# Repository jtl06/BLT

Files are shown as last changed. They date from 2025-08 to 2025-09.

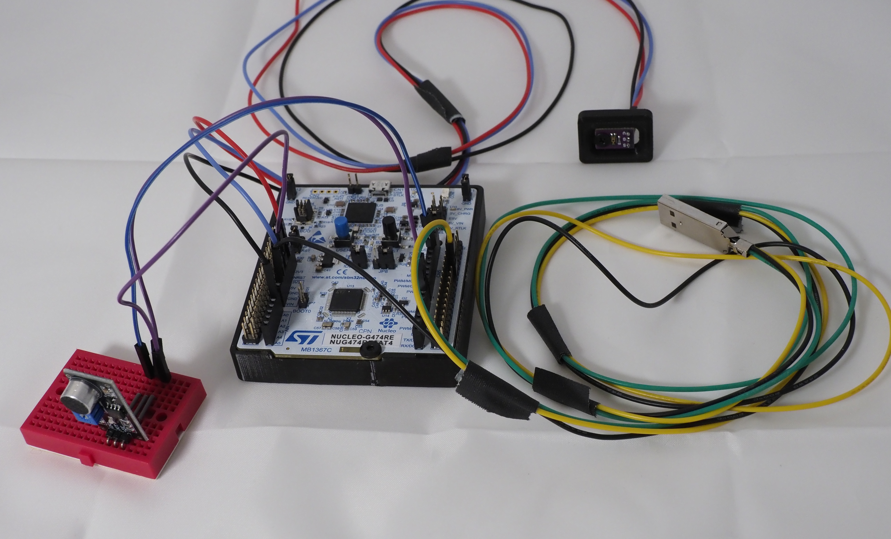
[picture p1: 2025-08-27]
docs/pictures/everything.JPG

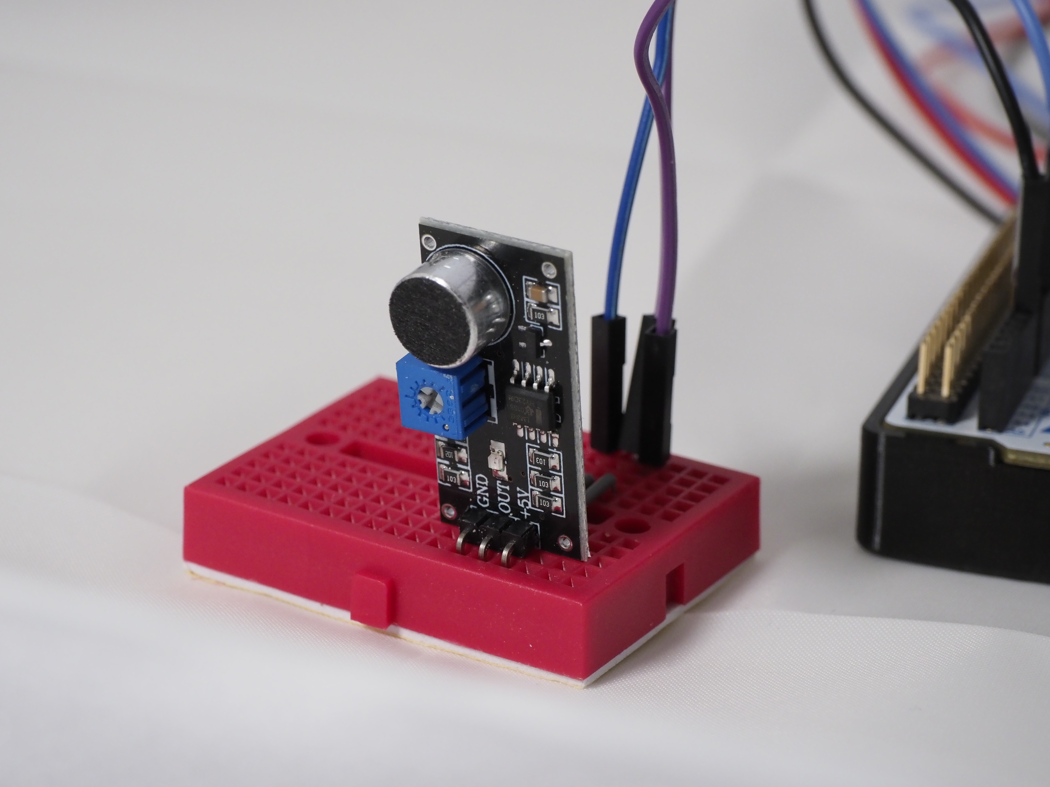
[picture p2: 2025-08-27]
docs/pictures/microphone.JPG

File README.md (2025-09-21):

# BLT - Better Latency Tester
The Better Latency Tester (BLT) is an open device for click to photon latency measurements in video games. It enables evaluation of game settings, monitors, and mice through reproducible, end-to-end latency data.

BLT features include:
- Automatic or manual threshold calibration
- Run batched, self-triggered tests via USB mouse HID inputs, with latency logging
- Microphone triggered tests for testing mouse latency

---
## Demo
https://github.com/user-attachments/assets/7085f5da-f47d-4a11-8dff-cdf1d9c3fb22
TEMT6000 Phototransistor Module             |  BLT Hardware
:-------------------------:|:-------------------------:
   |  

## Limitations
- Numbers should only be used to compare relative values, as the BLT has not been calibrated against an external reference such as a high speed (1000fps+) camera.
- Sample size requirements, latency results are randomly distributed, to get statistically significant results, a large amount of samples is required.

## Sample Data
### Vsync On vs Off vs Reflex
| Settings | n | Median | Mean | Std Dev | Min | Max |
|---|-----|---|---|---|---|---|
| 60hz, 60fps, Vsync On, Reflex Off | 100 | 74.101 | 74.507 | 5.222 | 66.134 | 93.211 |
| 60hz, 60fps, Vsync On, Reflex On | 100 | 74.951 | 74.572 | 4.871 | 66.426 | 82.621 |
| 60hz, 64fps Vsync Off, Reflex Off | 100 | 31.338  | 31.316  | 6.524 | 18.439 | 45.391 |
| 60hz, 64fps Vsync Off, Reflex On  | 100 | 27.529  | 27.335  | 6.268 | 6.569 | 40.024 |
| 240hz, 240fps, Vsync On, Reflex Off | 100 | 13.261 | 13.839 | 2.507 | 9.621 | 19.396 |
| 240hz, 240fps, Vsync On, Reflex On | 100 | 13.359 | 13.898 | 2.521 | 4.972 | 20.301 |
| 240hz, 240fps Vsync Off, Reflex Off | 100 | 10.304  | 10.457  | 1.900 | 5.338 | 15.056 |
| 240hz, 240fps Vsync Off, Reflex On  | 100 | 10.599  | 10.479  | 1.967 | 6.098 | 16.648 |

Tested in Counter-Strike 2, times in ms. Low settings. See docs for raw data. Note: CS2 implements a minimum framerate cap of 64fps when not using vsync.

### Reflex, with higher GPU Load (to maximize impact of render pipeline load)
|Settings|n|Median|Mean|Std Dev|Min|Max|
|---|-----|---|---|---|---|---|
|240hz, uncapped (~220fps), Vsync Off, Reflex Off|100|17.723|17.586|2.213|5.388|22.063|
|240hz, uncapped (~220fps),  Vsync Off, Reflex On|100|14.364|14.361|1.862|8.834|18.980|

High settings test, with greater GPU load, Reflex has a larger, more measurable improvement.  

### Mouse Testing using Mic Mode
| Settings | n | Median | Mean | Std Dev | Min | Max |
|---|-----|---|---|---|---|---|
| VXE MAD R, 125hz | 25 | 24.294  | 24.677 | 2.441 | 21.067 | 29.780 |
| VXE MAD R, 250hz | 25 | 21.855 | 21.915 | 1.775 | 18.865 | 25.430 |
| VXE MAD R, 500hz | 25 | 21.030  | 21.324  | 1.726 | 17.996 | 24.752 |
| VXE MAD R, 1000hz  | 25 | 20.561 | 20.346 | 1.506 | 17.291 | 22.533 |
| VXE MAD R, 2000hz | 25 | 20.566 | 20.729 | 1.588 | 17.852 | 23.397 |
| VXE MAD R, 4000hz | 25 | 20.518 | 20.561 | 1.100 | 19.012 | 23.409 |
| VXE MAD R, 8000hz| 25 | 19.558  | 20.029  | 1.572 | 17.983 | 23.513 |
| Razer Viper Pro V2, 4000hz  | 25 | 20.146  | 20.056  | 1.386 | 17.637 | 23.038 |
| Trigger Mode, 1000hz  | 100 | 20.146  | 20.056  | 1.386 | 17.637 | 23.038 |

Tested at 240hz, Low settings, Reflex On. At these sample size, could not find significant improvement above 1khz. TODO: Larger sample sizes

## Requirements
### Hardware
- NUCLEO-G474RE (or compatible STM32 with USB FS + ADC)
- TEMT6000 phototransistor (or photodiode)
- LM393 microphone module
- 2 USB cables (one for ST-Link serial comms, one for the USB HID Device)
### Software
- [Arm GNU Toolchain](https://developer.arm.com/downloads/-/arm-gnu-toolchain) (arm-none-eabi-gcc, make)
- [STM32CubeMX](https://www.st.com/en/development-tools/stm32cubemx.html) (for .ioc regeneration)
- Python 3.9+ (for PC app)

## Instructions
### HW Pinout  
| Function | MCU Pin | Periph/Chan | Notes |
|---|---|---|---|
| **USB D+/D-** | PA12/PA11 | USB_FS | To PC (mouse HID signal) |
| **Light Sensor (Photodiode/PT)**  | PA0 | ADC1 INx | Analog input |
| **Microphone (click detect)** | PA8 | GPIO | LM393 microphone module|
| **Serial Comms** | PA2/PA3 | LPUART TX/RX | Bidirectional communications for app control|
### Flashing
Flash via ST-LINK, using makefile and command ```make flash```

### Operation
1. Plug the USB cable from the board into your PC under test (should enumerate as a USB HID device).
2. Place the photodiode over the area that will recieve the flash. If using mic mode, place the microphone module near the mouse click.
3. Windows: launch the prebuilt GUI executable BLT-gui.exe, Linux/macOS: run the Python app directly with ```python blt_gui.py```
4. Follow GUI to Set Mode, Calibrate, and Test. Data can be exported via CSV.

## Architecture
- MCU
  - USB HID mouse
  - ADC w/ circular DMA: light sensor
  - 1Mhz TIM clock for 1us resolution
  - LPUART over ST-Link VCP: command IO and telemetry

## Timing
BLT

Mode 2: USB Trigger, latency = t<sub>1</sub> - t<sub>0</sub>u

Mode 3: Mic Trigger, latency = t<sub>1</sub> - t<sub>0</sub>m

ISR period stats: avg=400 us, min=391 us, max=409 us, jitter=±9 us

## Roadmap
- Finish Readme
- Linux Sidecar for data handling
- Custom PCB for manufacturing
- Switch to MCU/board with USB HS PHY support for 8khz polling rate

> Inspired by the NVIDIA LDAT. This project is independent and unaffiliated with NVIDIA.

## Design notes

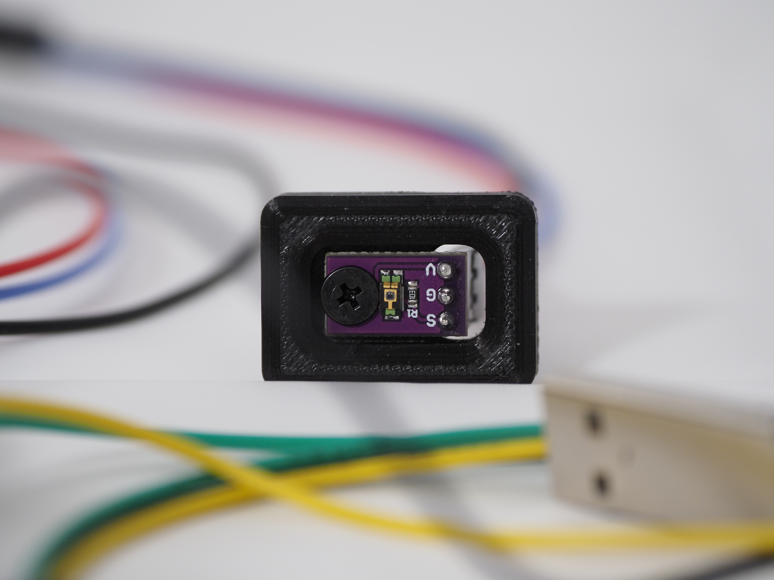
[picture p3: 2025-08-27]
docs/pictures/phototransistor.JPG

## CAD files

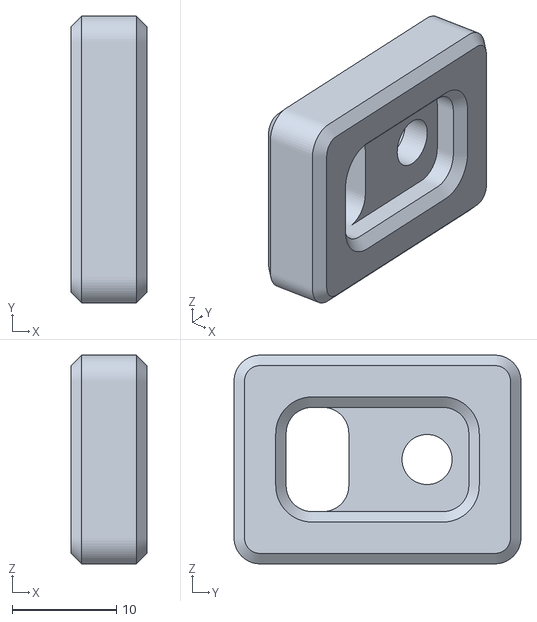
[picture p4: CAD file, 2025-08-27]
CAD files/TEMT6000 Case.stl
7.25 x 27.5 x 20.0

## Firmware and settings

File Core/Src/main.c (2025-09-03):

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
/* Includes ------------------------------------------------------------------*/
#include "main.h"
#include "adc.h"
#include "dma.h"
#include "usart.h"
#include "tim.h"
#include "usb_device.h"
#include "gpio.h"

/* USER CODE BEGIN Includes */
#include "usbd_hid.h"
#include <stdio.h>
#include <stdbool.h>
#include <stdint.h>
#include <string.h>
#include <stdlib.h>
#include <inttypes.h>
#include "isr_log.h"


/* USER CODE END Includes */

/* USER CODE BEGIN PTD */
typedef enum {
  MODE1_CALIBRATION = 1,
  MODE2_TRIGGER     = 2,
  MODE3_MIC         = 3,
} blt_mode_t;

/* USER CODE END PTD */

/* USER CODE BEGIN PD */
#define FW_VERSION "BLT 0.1.1"

#define ADC_BUF_LEN 256u
#define MODE2_SPACING_US 5000000u // 5 s
#define MIC_DEBOUNCE_US 200000u  // 200 ms

#define ADC_SAMPLE_PERIOD_US 3u // 3us

/* USER CODE END PD */


/* USER CODE BEGIN PV */
extern USBD_HandleTypeDef hUsbDeviceFS;

static uint16_t          g_light_threshold = 200;
static volatile uint32_t g_tests_remaining = 0;
static uint32_t          g_trial_idx = 0;

static volatile bool     g_waiting_for_light = false;
static volatile uint32_t g_t_start_us = 0;
static uint32_t          g_last_launch_us = 0;
static volatile uint32_t g_last_mic_us = 0;

static uint8_t  rx_byte;
static char     cmd_buf[96];
static uint8_t  cmd_len = 0;

volatile uint16_t g_adc_dma_buf[ADC_BUF_LEN];

static volatile blt_mode_t g_mode = MODE1_CALIBRATION;

static volatile uint32_t g_last_idx = 0;

//unused, for debug if needed
// static volatile bool g_btn_click_req = false; 



/* USER CODE END PV */

void SystemClock_Config(void);
/* USER CODE BEGIN PFP */
void send_mouse_click(void);
static inline uint16_t adc_latest_sample(void); 
static void uart_start_rx_it(void);
static void send_line(const char *s);
static void handle_cmd(const char *cmd);

static inline uint32_t adc_write_idx(void);
static bool detect_cross_and_stamp(uint16_t thr, uint32_t* t1_out);
static void isr_log_dump_stats(void);


/* USER CODE END PFP */

/* USER CODE BEGIN 0 */
int _write(int file, char *ptr, int len)
{
  HAL_UART_Transmit(&hlpuart1, (uint8_t*)ptr, len, HAL_MAX_DELAY);
  return len;
}

/* USER CODE END 0 */

/**
  * @brief  The application entry point.
  * @retval int
  */
int main(void)
{

  /* MCU Configuration--------------------------------------------------------*/

  /* Reset of all peripherals, Initializes the Flash interface and the Systick. */
  HAL_Init();

  /* Configure the system clock */
  SystemClock_Config();

  /* Initialize all configured peripherals */
  MX_GPIO_Init();
  MX_DMA_Init();
  MX_LPUART1_UART_Init();
  MX_ADC1_Init();
  MX_TIM2_Init();
  MX_USB_Device_Init();
  /* USER CODE BEGIN 2 */
  
  HAL_ADCEx_Calibration_Start(&hadc1, ADC_SINGLE_ENDED);

  if (HAL_ADC_Start_DMA(&hadc1, (uint32_t*)g_adc_dma_buf, ADC_BUF_LEN) != HAL_OK)
  {
    Error_Handler();
  }

  printf("Continuous ADC-DMA running, buf=%u samples\r\n", ADC_BUF_LEN);
  printf("Initialized %s\r\n", FW_VERSION);
  HAL_TIM_Base_Start(&htim2);
  uart_start_rx_it();
  // printf("%lu\n", USBD_HID_GetPollingInterval(&hUsbDeviceFS)); // send polling rate
  
  
  /* USER CODE END 2 */

  /* Infinite loop */
  /* USER CODE BEGIN WHILE */
while (1) {
  uint32_t now_us = tim2_us();

  // MODE2: launch trials periodically, using USB as trigger
  if (g_mode == MODE2_TRIGGER && g_tests_remaining && !g_waiting_for_light) {
    if ((now_us - g_last_launch_us) >= MODE2_SPACING_US) {
      g_last_launch_us = tim2_us();
      g_last_idx = adc_write_idx();
      g_t_start_us = tim2_us();  //start time
      g_waiting_for_light = true;
      send_mouse_click();
    }
  }
  __WFI();
    /* USER CODE END WHILE */

    /* USER CODE BEGIN 3 */
  }
  /* USER CODE END 3 */
}

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
/* USER CODE BEGIN 4 */
static inline uint16_t adc_latest_sample(void)
{
    uint32_t dma_remaining = __HAL_DMA_GET_COUNTER(&hdma_adc1);
    uint32_t idx           = (ADC_BUF_LEN - dma_remaining) & (ADC_BUF_LEN-1);
    return g_adc_dma_buf[idx];
}


static inline uint32_t adc_write_idx(void){
    // NDTR = how many transfers LEFT; write index = prod
    uint32_t ndtr = __HAL_DMA_GET_COUNTER(&hdma_adc1);
    return (ADC_BUF_LEN - ndtr) & (ADC_BUF_LEN - 1);
}

static bool detect_cross_and_stamp(uint16_t thr, uint32_t* t1_out){
    uint32_t write = adc_write_idx();
    uint32_t idx   = g_last_idx;

    while (idx != write) {
        uint16_t s = g_adc_dma_buf[idx];
        if (s >= thr) {
            uint32_t now = tim2_us(); // tim2 ticks
            // How far behind "now" that sample is, in samples (mod ring)
            uint32_t samples_behind = (write - idx) & (ADC_BUF_LEN - 1);
            // sample time = 3 us
            uint32_t ticks_behind = samples_behind * ADC_SAMPLE_PERIOD_US;
            *t1_out = now - ticks_behind;
            g_last_idx = write; // consume everything up to 'write'
            return true;
        }
        idx = (idx + 1) & (ADC_BUF_LEN - 1);
    }
    g_last_idx = write;
    return false;
}

void HAL_GPIO_EXTI_Callback(uint16_t GPIO_Pin) {
  if (GPIO_Pin == MIC1_Pin && g_mode == MODE3_MIC) {
    uint32_t now = tim2_us();
    if ((uint32_t)(now - g_last_mic_us) > MIC_DEBOUNCE_US) {
      g_last_mic_us = now;
      if (g_tests_remaining && !g_waiting_for_light) {
        g_waiting_for_light = true;
        g_t_start_us = now; // mic click time
      }
    }
  } // else if (GPIO_Pin == USER_BUTTON_Pin) {
    // g_btn_click_req = true; //unused, for debug if needed
  // }
}


void send_mouse_click(void)
{
  uint8_t hid_report[4] = {0};

  hid_report[0] = 0x01; 
  USBD_HID_SendReport(&hUsbDeviceFS, hid_report, sizeof(hid_report));
  HAL_Delay(1);

  hid_report[0] = 0x00;
  USBD_HID_SendReport(&hUsbDeviceFS, hid_report, sizeof(hid_report));
}

static void uart_start_rx_it(void) {
  HAL_UART_Receive_IT(&hlpuart1, &rx_byte, 1);
}

static inline void send_line(const char *s) {
  HAL_UART_Transmit(&hlpuart1, (uint8_t*)s, (uint16_t)strlen(s), HAL_MAX_DELAY);
}

void HAL_UART_RxCpltCallback(UART_HandleTypeDef *huart) {
  if (huart == &hlpuart1) {
    uint8_t c = rx_byte;

    if (c == '\n' || c == '\r') {
      if (cmd_len) {
        cmd_buf[cmd_len] = '\0';
        handle_cmd(cmd_buf);
        cmd_len = 0;
      }
    } else if (cmd_len < sizeof(cmd_buf)-1) {
      cmd_buf[cmd_len++] = (char)c;
    } else {
      cmd_len = 0;
    }
    HAL_UART_Receive_IT(&hlpuart1, &rx_byte, 1);
  }
}

static void handle_cmd(const char *cmd) {
  if (strcmp(cmd, "HELP") == 0) {
    send_line("CMDS: HELLO, HELP, VERSION, STATUS, "
              "MODE1, MODE2, MODE3, CAL READ, CAL AUTO, CAL SET <thr>, TEST START <n>\r\n");

  } else if (strcmp(cmd, "HELLO") == 0) {
    send_line("ACK HELLO\r\n");

  } else if (strcmp(cmd, "VERSION") == 0) {
    char b[48]; snprintf(b, sizeof b, "VERSION %s\r\n", FW_VERSION); send_line(b);

  } else if (strcmp(cmd, "STATUS") == 0) {
    char b[96];
    snprintf(b, sizeof b, "STATUS mode=%u light=%u thr=%u waiting=%u left=%lu\r\n",
             (unsigned)g_mode, (unsigned)adc_latest_sample(), (unsigned)g_light_threshold,
             (unsigned)g_waiting_for_light, (unsigned long)g_tests_remaining);
    send_line(b);

  // Modes 
  } else if (strcmp(cmd, "MODE1") == 0) {
    g_mode = MODE1_CALIBRATION;  send_line("ACK MODE1\r\n");

  } else if (strcmp(cmd, "MODE2") == 0) {
    g_mode = MODE2_TRIGGER;      send_line("ACK MODE2\r\n");

  } else if (strcmp(cmd, "MODE3") == 0) {
    g_mode = MODE3_MIC;          send_line("ACK MODE3\r\n");

  // Calibration
  } else if (strcmp(cmd, "CAL READ") == 0) {
    char b[64];
    snprintf(b, sizeof b, "CAL,light=%u,thr=%u\r\n", (unsigned)adc_latest_sample(), (unsigned)g_light_threshold);
    send_line(b);

  } else if (strcmp(cmd, "CAL AUTO") == 0) {
    uint32_t thr = (adc_latest_sample() * 125u) / 100u;  // +25%
    if (thr > 4095u) thr = 4095u;
    g_light_threshold = (uint16_t)thr;
    char b[48];
    snprintf(b, sizeof b, "ACK CAL SET %u\r\n", (unsigned)g_light_threshold);
    send_line(b);

  } else if (strncmp(cmd, "CAL SET ", 8) == 0) {
    uint32_t v = strtoul(cmd+8, NULL, 10);
    if (v > 4095u) v = 4095u;
    g_light_threshold = (uint16_t)v;
    char b[48];
    snprintf(b, sizeof b, "ACK CAL SET %u\r\n", (unsigned)g_light_threshold);
    send_line(b);

  // Test arming
  } else if (strncmp(cmd, "TEST START ", 11) == 0) {
    uint32_t n = strtoul(cmd+11, NULL, 10);
    g_trial_idx = 0;
    g_tests_remaining = n;
    g_waiting_for_light = false;
    send_line("DATA,trial,latency_us,light\r\n");  // CSV header
    char b[64];
    snprintf(b, sizeof b, "ACK TEST START %lu\r\n", (unsigned long)n);
    send_line(b);

    // MODE2: optionally launch first trial immediately
    if (g_mode == MODE2_TRIGGER && g_tests_remaining) {
      g_last_launch_us = tim2_us() - MODE2_SPACING_US; // so it fires right away
    }
  
  //return jitter
  } else if (strcmp(cmd, "JIT") == 0) {
    isr_log_dump_stats();
    isr_log_reset();
  } else {
    send_line("ERR UNKNOWN\r\n");
  }
}

void HAL_UART_ErrorCallback(UART_HandleTypeDef *huart) {
  if (huart == &hlpuart1) {
    __HAL_UART_CLEAR_OREFLAG(huart);
    HAL_UART_Receive_IT(&hlpuart1, &rx_byte, 1);
  }
}

void HAL_ADC_ConvHalfCpltCallback(ADC_HandleTypeDef* hadc)
{
    (void)hadc;
    if (g_waiting_for_light) {
        uint32_t t1;
        if (detect_cross_and_stamp(g_light_threshold, &t1)) {
            uint32_t dt_us = (uint32_t)(t1 - g_t_start_us);
            ++g_trial_idx;
            char out[96];
            int n = snprintf(out, sizeof out, "DATA,%lu,%lu,%u\r\n",
                             (unsigned long)g_trial_idx,
                             (unsigned long)dt_us,
                             (unsigned)adc_latest_sample());
            HAL_UART_Transmit(&hlpuart1, (uint8_t*)out, (uint16_t)n, HAL_MAX_DELAY);

            g_waiting_for_light = false;
            if (--g_tests_remaining == 0) {
                send_line("DONE\r\n");
            }
        }
    }
}

void HAL_ADC_ConvCpltCallback(ADC_HandleTypeDef* hadc)
{
    // Same handling at full-complete boundary
    HAL_ADC_ConvHalfCpltCallback(hadc);
}

void isr_log_dump_stats(void) {
    uint16_t n = isr_log_count();
    if (n < 2) { printf("not enough samples\n"); return; }

    uint32_t prev = isr_log_get(0);
    uint64_t sum  = 0;
    uint32_t min_d = 0xFFFFFFFFu, max_d = 0;

    for (uint16_t i = 1; i < n; i++) {
        uint32_t curr  = isr_log_get(i);
        uint32_t delta = (curr - prev);   // unsigned handles 32-bit wrap
        prev = curr;

        if (delta < min_d) min_d = delta;
        if (delta > max_d) max_d = delta;
        sum += delta;
    }

    uint32_t count_periods = n - 1;
    uint32_t avg = (uint32_t)(sum / count_periods);
    uint32_t pkpk = max_d - min_d;

    printf("ISR period stats: count=%" PRIu16 " , avg=%" PRIu32 " us, min=%" PRIu32 " us, max=%" PRIu32 " us, jitter=±%" PRIu32 " us\n",
           n, avg, min_d, max_d, pkpk/2);
}

/* USER CODE END 4 */
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


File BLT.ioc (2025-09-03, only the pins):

Mcu.UserName=STM32G474RETx
PA0.Signal=ADC1_IN1
PA11.Signal=USB_DM
PA12.Signal=USB_DP
PA13.Signal=SYS_JTMS-SWDIO
PA14.Signal=SYS_JTCK-SWCLK
PA2.Signal=LPUART1_TX
PA3.Signal=LPUART1_RX
PA5.GPIO_Label=USER_LED
PA5.Signal=GPIO_Output
PA8.GPIO_Label=MIC1
PA8.Signal=GPXTI8
PC13.GPIO_Label=USER_BUTTON
PC13.Signal=GPXTI13

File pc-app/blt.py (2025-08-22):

import sys, time, csv
from pathlib import Path
from statistics import mean, median, pstdev
from PySide6 import QtCore, QtGui, QtWidgets
import serial, serial.tools.list_ports

EOL = b"\n"   # your firmware accepts LF or CRLF; we'll send LF

# ---------- Serial worker (runs in its own thread) ----------
class SerialWorker(QtCore.QObject):
    line = QtCore.Signal(str)
    status = QtCore.Signal(str)
    connected = QtCore.Signal(bool)

    def __init__(self):
        super().__init__()
        self._ser = None
        self._running = False
        self._buf = bytearray()

    @QtCore.Slot(str, int)
    def start(self, port: str, baud: int):
        self.stop()
        try:
            self._ser = serial.Serial(port=port, baudrate=baud, timeout=0.05)
            self._running = True
            self.connected.emit(True)
            self.status.emit(f"Connected {port} @ {baud}")
        except Exception as e:
            self._ser = None
            self.connected.emit(False)
            self.status.emit(f"ERROR opening {port}: {e}")
            return
        QtCore.QTimer.singleShot(0, self._pump)

    @QtCore.Slot()
    def stop(self):
        self._running = False
        if self._ser and self._ser.is_open:
            try: self._ser.close()
            except: pass
        self._ser = None
        self.connected.emit(False)

    def _pump(self):
        if not self._running or not self._ser:
            return
        try:
            data = self._ser.read(1024)
            if data:
                self._buf.extend(data)
                while True:
                    # look for LF first, else CR
                    i_n = self._buf.find(b"\n")
                    i_r = self._buf.find(b"\r")
                    idxs = [i for i in (i_n, i_r) if i != -1]
                    if not idxs:
                        break
                    i = min(idxs)
                    raw = bytes(self._buf[:i])        # bytes up to delimiter
                    # remove the line + delimiter (+ optional CRLF partner)
                    rm = 1
                    if i + 1 < len(self._buf) and self._buf[i] in (13,10) and self._buf[i+1] in (13,10) and self._buf[i+1] != self._buf[i]:
                        rm = 2
                    del self._buf[:i + rm]
                    s = raw.decode("utf-8", errors="replace").strip()
                    if s:
                        self.line.emit(s)
        except Exception as e:
            self.status.emit(f"Serial read error: {e}")
            self.stop()
            return
        QtCore.QTimer.singleShot(5, self._pump)

    @QtCore.Slot(str)
    def write_line(self, s: str):
        if not self._ser or not self._ser.is_open: return
        try:
            self._ser.write(s.encode("utf-8") + EOL)
        except Exception as e:
            self.status.emit(f"Serial write error: {e}")

# ---------- Table model ----------
class DataModel(QtGui.QStandardItemModel):
    def __init__(self):
        super().__init__(0, 3)
        self.setHorizontalHeaderLabels(["trial", "latency_us", "light"])

    def add_row(self, trial:int, latency:int, light:int):
        items = [
            QtGui.QStandardItem(str(trial)),
            QtGui.QStandardItem(str(latency)),
            QtGui.QStandardItem(str(light)),
        ]
        for it in items: it.setEditable(False)
        self.appendRow(items)

    def clear_data(self):
        self.setRowCount(0)

    def latency_values(self):
        vals = []
        for r in range(self.rowCount()):
            try:
                vals.append(int(self.item(r,1).text()))
            except: pass
        return vals

# ---------- Main window ----------
class MainWindow(QtWidgets.QMainWindow):
    def __init__(self):
        super().__init__()
        self.setWindowTitle("JTL BLT")
        self.resize(980, 640)

        # state
        self.connected = False

        # serial thread
        self.thread = QtCore.QThread(self)
        self.worker = SerialWorker()
        self.worker.moveToThread(self.thread)
        self.thread.start()

        # UI
        self._build_ui()

        # signals
        self.worker.line.connect(self.on_line)
        self.worker.status.connect(self.log)
        self.worker.connected.connect(self.on_connected)

        # populate ports
        self.refresh_ports()

    # ---- UI layout ----
    def _build_ui(self):
        central = QtWidgets.QWidget()
        self.setCentralWidget(central)
        lay = QtWidgets.QVBoxLayout(central)

        # Top bar: port/baud/connect
        top = QtWidgets.QHBoxLayout()
        self.port_cb = QtWidgets.QComboBox()
        self.refresh_btn = QtWidgets.QPushButton("Refresh")
        self.baud_cb = QtWidgets.QComboBox()
        self.baud_cb.addItems(["115200","230400","460800","921600"])
        self.baud_cb.setCurrentText("115200")
        self.connect_btn = QtWidgets.QPushButton("Connect")
        self.disconnect_btn = QtWidgets.QPushButton("Disconnect")
        self.disconnect_btn.setEnabled(False)
        top.addWidget(QtWidgets.QLabel("Port:"))
        top.addWidget(self.port_cb, 2)
        top.addWidget(self.refresh_btn)
        top.addSpacing(10)
        top.addWidget(QtWidgets.QLabel("Baud:"))
        top.addWidget(self.baud_cb)
        top.addSpacing(10)
        top.addWidget(self.connect_btn)
        top.addWidget(self.disconnect_btn)
        lay.addLayout(top)

        # Mode + calibration controls
        modebar = QtWidgets.QHBoxLayout()
        self.mode_cb = QtWidgets.QComboBox()
        self.mode_cb.addItems(["MODE1 (Calibrate)","MODE2 (Trigger)","MODE3 (Mic)"])
        self.set_mode_btn = QtWidgets.QPushButton("Set Mode")
        self.cal_read_btn = QtWidgets.QPushButton("CAL READ")
        self.cal_auto_btn = QtWidgets.QPushButton("CAL AUTO")
        self.cal_set_spin = QtWidgets.QSpinBox(); self.cal_set_spin.setRange(0, 4095); self.cal_set_spin.setValue(100)
        self.cal_set_btn = QtWidgets.QPushButton("CAL SET")
        modebar.addWidget(self.mode_cb)
        modebar.addWidget(self.set_mode_btn)
        modebar.addSpacing(10)
        modebar.addWidget(self.cal_read_btn)
        modebar.addWidget(self.cal_auto_btn)
        modebar.addWidget(QtWidgets.QLabel("thr:"))
        modebar.addWidget(self.cal_set_spin)
        modebar.addWidget(self.cal_set_btn)
        lay.addLayout(modebar)
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

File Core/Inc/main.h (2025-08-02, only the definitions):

#define USER_BUTTON_Pin GPIO_PIN_13
#define USER_BUTTON_GPIO_Port GPIOC
#define USER_BUTTON_EXTI_IRQn EXTI15_10_IRQn
#define USER_LED_Pin GPIO_PIN_5
#define USER_LED_GPIO_Port GPIOA
#define MIC1_Pin GPIO_PIN_8
#define MIC1_GPIO_Port GPIOA
#define MIC1_EXTI_IRQn EXTI9_5_IRQn

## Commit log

2025-08-01 replaced stm32h533 with g474, h533 had hardware issue, added sound detection for mouse input, TODO: re-implement light change detection and timing
    [jtl_ldat.ioc, main.c, main.h]
2025-08-02 reimplemented timing, adding full latency detection and calibration mode
2025-08-12 changed ADC to use DMA for efficiency
2025-08-13 changed to custom HID device
2025-08-16 added bidirectional serial comms, and prototype app
2025-08-19 added PC app, minor bugfixes
    [ldat_gui.py, main.c]
2025-08-25 fixed 100hz polling rate bug
    [main.c]
2025-08-25 added sample data
    [blt_data_cs2_270hz_vsync.csv]
2025-08-26 added 3d printed case for phototransistor module
    [TEMT6000 Case.stl]
2025-08-27 added pics, updated readme, minor name changes
    [TEMT6000 Case.stl, blt_data_cs2_270hz_vsync.csv]
2025-08-28 added more sample data
    [blt_data_270hz_novsync_reflexon.csv, blt_data_cs2_270hz_novsync_noreflex.csv, blt_data_cs2_270hz_novsync_reflexon.csv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]
2025-08-29 fixed ADC DMA loop to prevent bug
    [BLT.ioc, main.c]
2025-08-29 updated readme, updated sample data
    [blt_data_270hz_novsync_reflexon.csv, blt_data_cs2_270hz_novsync_noreflex.csv, blt_data_cs2_270hz_novsync_reflexon.csv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]
2025-09-01 updated readme, more sample data, minor tweaks to debounce times for mic trigger
    [cs2_high_uncapped_240hz.csv, cs2_high_uncapped_240hz_reflex.csv]
2025-09-03 switched to HAL init as a seperate pair of .c and .h file per peripheral
2025-09-03 added local copy of openocd cfg files
    [blt.cfg, stlink.cfg, stm32g4x.cfg]
2025-09-03 added timestamping for ISR and jitter measurements
    [main.c]

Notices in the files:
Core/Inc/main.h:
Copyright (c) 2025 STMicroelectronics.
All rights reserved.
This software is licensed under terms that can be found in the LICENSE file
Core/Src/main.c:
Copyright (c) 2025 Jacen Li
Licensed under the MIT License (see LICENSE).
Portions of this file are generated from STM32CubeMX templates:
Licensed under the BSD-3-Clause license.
